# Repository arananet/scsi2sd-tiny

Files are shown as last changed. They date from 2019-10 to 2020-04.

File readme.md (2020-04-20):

# SCSI2SD

SCSI2SD is an open project made by Michael McMaster that replace your old SCSI drive device with a SCSI emulator using micro-sd.

# SCSI-TINY

I made this new tiny design from the original SCSI2SD schematics using EAGLE PCB Software. This particular design contains two SD sockets, one for micro-sd and one for SD. This is a working and tested design by many users. They are on sale in AmigaStore and also a batch has been made in 2018 for the RETROWIKI forum.

# Updates

25/10/2019: Initial release. HW made in 2018.

# License

SCSI2SD copyright (c) Michael McMaster | http://www.codesrc.com/mediawiki/index.php?title=SCSI2SD

SCSI2SD-Tiny copyright (c) 2018 Eduardo Arana | @edu_arana

This project is released under the GNU v3 license. You can redistribute it and/or modify it under the terms of the GNU General Public License as published by the Free Software Foundation, either version 3 of the License, or (at your option) any later version.

This program is distributed in the hope that it will be useful, but WITHOUT ANY WARRANTY.

See the GNU General Public License for more details.

There is a copy of the GPLv3 license in this repository. If not, see http://www.gnu.org/licenses/.

## The source/designs of any modifications must be provided to those you distribute the board to.

# Feedback

If you find any error on this description, please drop me an email to info@arananet.net or # Feedback

If you find any error on this description, please drop me an email to info@arananet.net or If you like the project or want to support it, you can buy me a beer or a KO-FI :) 


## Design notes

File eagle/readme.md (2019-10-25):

If you are gonna produce a batch of this board remember to quote the original authors, don't be a pcb lammer, leave the original authors on the PCB.

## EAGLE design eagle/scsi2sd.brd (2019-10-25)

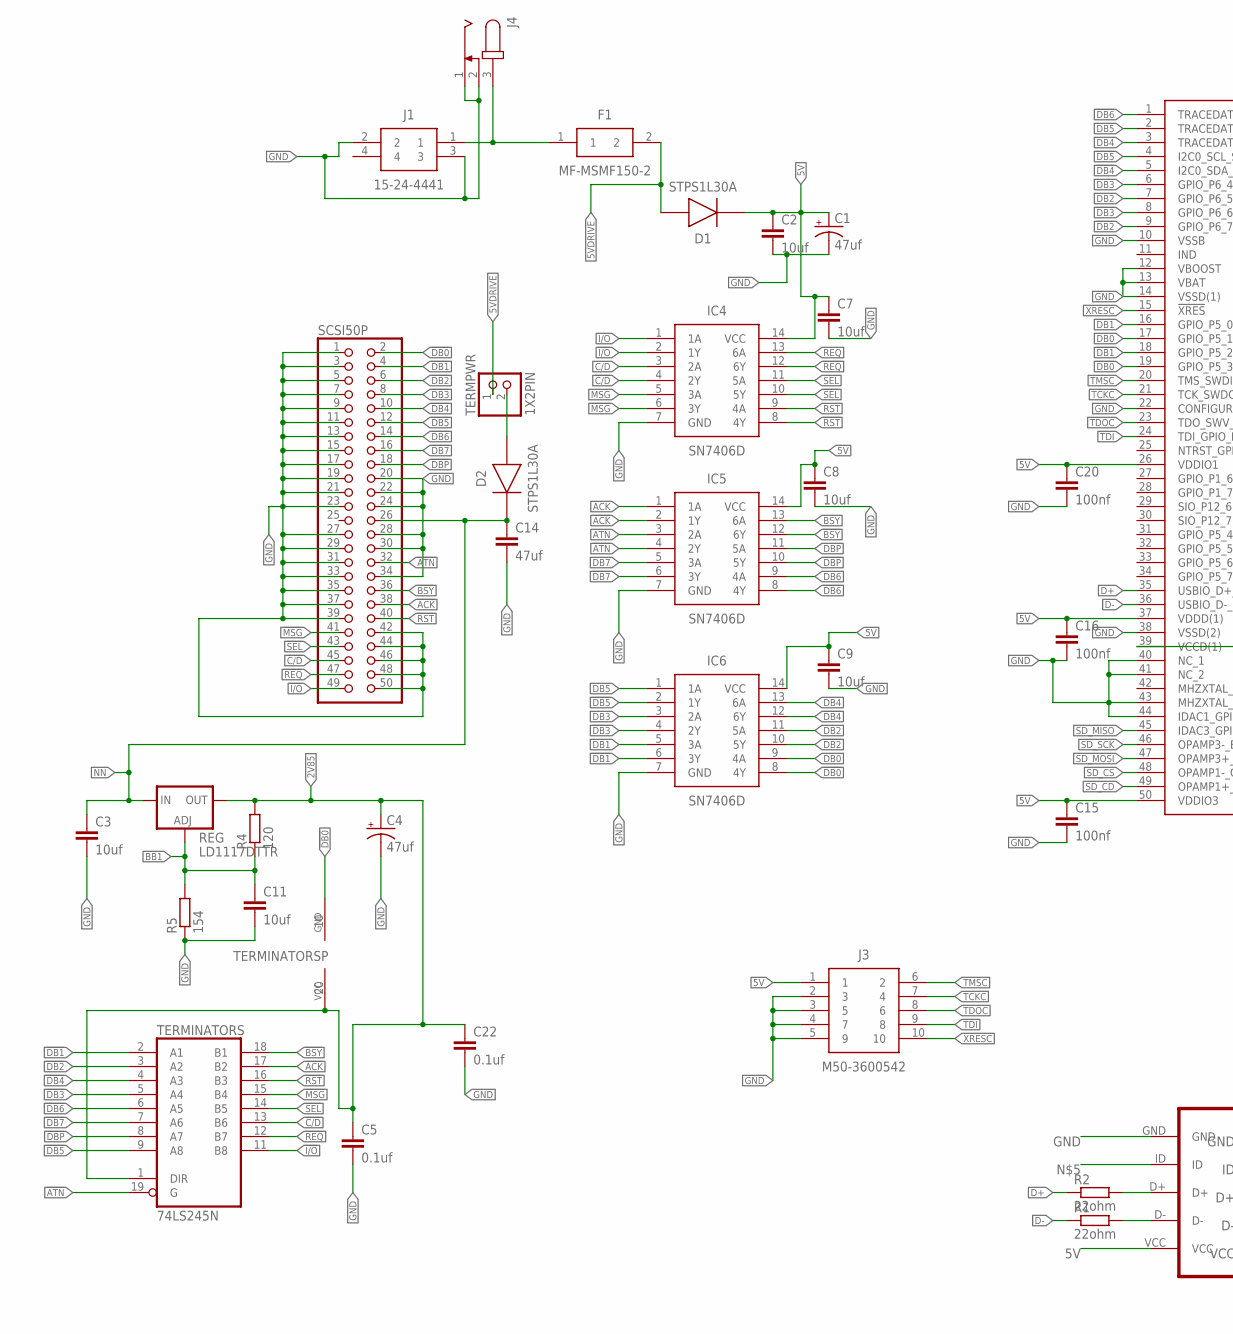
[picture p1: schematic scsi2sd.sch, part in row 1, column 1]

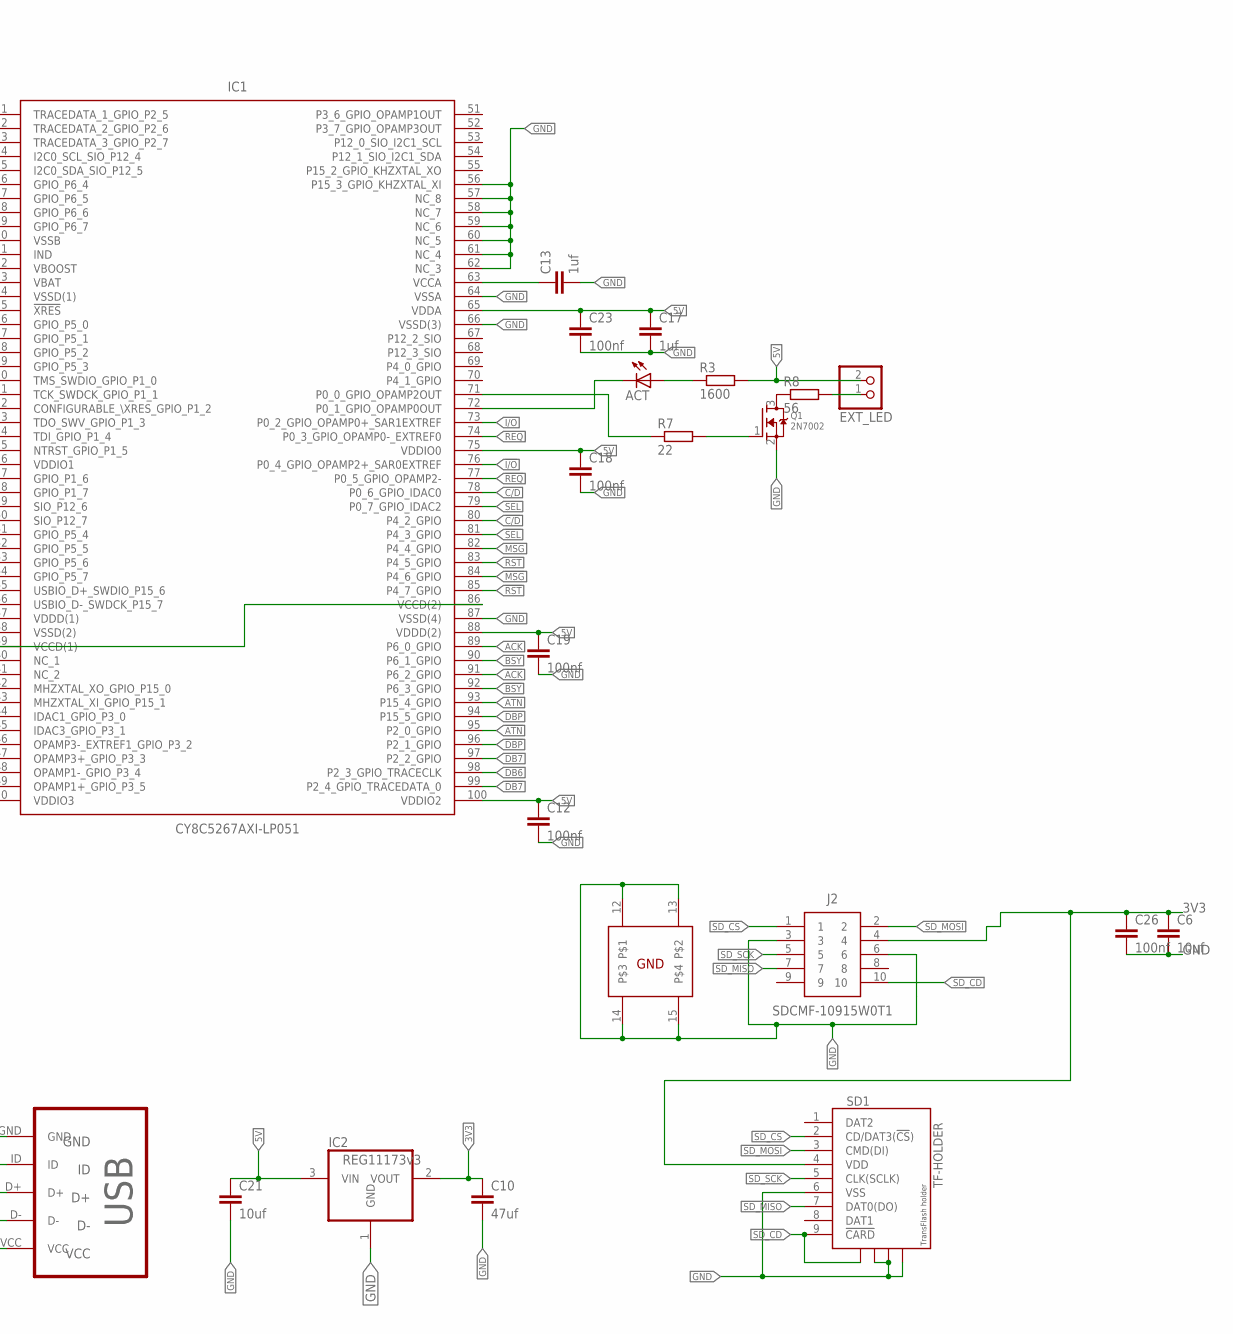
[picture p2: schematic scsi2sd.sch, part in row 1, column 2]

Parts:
ACT: LEDCHIPLED_0805; CHIPLED_0805
C1, C4: 47uf; E2,5-5
C2, C3, C6, C7, C8, C9, C11, C21: 10uf; C0603
C5, C22: 0.1uf; C0603
C10: 47uf; C0603
C12, C15, C16, C18, C19, C20, C23, C26: 100nf; C0603
C13, C17: 1uf; C0603
C14: 47uf; C1206
D1, D2: STPS1L30A; DIOM5226X223N
EXT_LED: 1X2PIN
F1: MF-MSMF150-2; FUSC4632X85N
IC1: CY8C5267AXI-LP051; TQFP50P1600X1600X160-100N
IC2: REG11173v3; SOT223
IC4, IC5, IC6: SN7406D; SOIC127P600X175-14N
J1: 15-24-4441
J2: SDCMF-10915W0T1
J3: M50-3600542; HARWIN_10PIN_1.27PITCH_SMD
J4: RAPC7120; RAPC712
Q1: 2N7002; SOT23
R1, R2: 22ohm; R0603
R3: 1600; R0603
R4: 120; R0603
R5: 154; R0603
R7: 22; R0603
R8: 56; R0603
REG: LD1117DTTR; DPACK
SCSI50P: PINHD-2X25/90; 2X25/90
SD1: TF-HOLDER; TF-PULL
TERMINATORS: 74LS245N; DIL20
TERMPWR: 1X2PIN
USB: MICRO-USB-B; MICRO_USB_4_LEGS

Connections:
2V85: C4.+, C5.1, C22.1, R4.2, REG.4 (OUT), TERMINATORS.1 (DIR), TERMINATORS.20 (VCC)
3V3: C6.1, C10.1, C26.1, IC2.2 (VOUT), J2.4, SD1.4 (VDD)
5V: C1.+, C2.1, C7.1, C8.1, C9.1, C12.1, C15.1, C16.1, C17.1, C18.1, C19.1, C20.1, C21.1, C23.1, D1.1 (K), EXT_LED.2, IC1.26 (VDDIO1), IC1.37 (VDDD(1)), IC1.50 (VDDIO3), IC1.65 (VDDA), IC1.75 (VDDIO0), IC1.88 (VDDD(2)), IC1.100 (VDDIO2), IC2.3 (VIN), IC4.14 (VCC), IC5.14 (VCC), IC6.14 (VCC), J3.1, R3.2, USB.VCC
5VDRIVE: D1.2 (A), F1.2, TERMPWR.1
!ACK: IC1.91 (P6_2_GPIO), IC5.2 (1Y), SCSI50P.38, TERMINATORS.17 (B2)
!ATN: IC1.95 (P2_0_GPIO), IC5.4 (2Y), SCSI50P.32, TERMINATORS.19 (G)
!BSY: IC1.92 (P6_3_GPIO), IC5.12 (6Y), SCSI50P.36, TERMINATORS.18 (B1)
!C/D: IC1.80 (P4_2_GPIO), IC4.4 (2Y), SCSI50P.45, TERMINATORS.13 (B6)
!DB0: IC1.19 (GPIO_P5_3), IC6.8 (4Y), SCSI50P.2, TERMINATORS.10 (GND)
!DB1: IC1.18 (GPIO_P5_2), IC6.6 (3Y), SCSI50P.4, TERMINATORS.2 (A1)
!DB2: IC1.9 (GPIO_P6_7), IC6.10 (5Y), SCSI50P.6, TERMINATORS.3 (A2)
!DB3: IC1.8 (GPIO_P6_6), IC6.4 (2Y), SCSI50P.8, TERMINATORS.5 (A4)
!DB4: IC1.5 (I2C0_SDA_SIO_P12_5), IC6.12 (6Y), SCSI50P.10, TERMINATORS.4 (A3)
!DB5: IC1.4 (I2C0_SCL_SIO_P12_4), IC6.2 (1Y), SCSI50P.12, TERMINATORS.9 (A8)
!DB6: IC1.1 (TRACEDATA_1_GPIO_P2_5), IC5.8 (4Y), SCSI50P.14, TERMINATORS.6 (A5)
!DB7: IC1.99 (P2_4_GPIO_TRACEDATA_0), IC5.6 (3Y), SCSI50P.16, TERMINATORS.7 (A6)
!DBP: IC1.96 (P2_1_GPIO), IC5.10 (5Y), SCSI50P.18, TERMINATORS.8 (A7)
!I/O: IC1.76 (P0_4_GPIO_OPAMP2+_SAR0EXTREF), IC4.2 (1Y), SCSI50P.49, TERMINATORS.11 (B8)
!MSG: IC1.84 (P4_6_GPIO), IC4.6 (3Y), SCSI50P.41, TERMINATORS.15 (B4)
!REQ: IC1.77 (P0_5_GPIO_OPAMP2-), IC4.12 (6Y), SCSI50P.47, TERMINATORS.12 (B7)
!RST: IC1.85 (P4_7_GPIO), IC4.8 (4Y), SCSI50P.40, TERMINATORS.16 (B3)
!SEL: IC1.81 (P4_3_GPIO), IC4.10 (5Y), SCSI50P.43, TERMINATORS.14 (B5)
ACK: IC1.89 (P6_0_GPIO), IC5.1 (1A)
ATN: IC1.93 (P15_4_GPIO), IC5.3 (2A)
BB1: C11.1, R4.1, R5.2, REG.1 (ADJ)
BSY: IC1.90 (P6_1_GPIO), IC5.13 (6A)
C/D: IC1.78 (P0_6_GPIO_IDAC0), IC4.3 (2A)
D+: IC1.35 (USBIO_D+_SWDIO_P15_6), R2.1
D-: IC1.36 (USBIO_D-_SWDCK_P15_7), R1.1
DB0: IC1.17 (GPIO_P5_1), IC6.9 (4A)
DB1: IC1.16 (GPIO_P5_0), IC6.5 (3A)
DB2: IC1.7 (GPIO_P6_5), IC6.11 (5A)
DB3: IC1.6 (GPIO_P6_4), IC6.3 (2A)
DB4: IC1.3 (TRACEDATA_3_GPIO_P2_7), IC6.13 (6A)
DB5: IC1.2 (TRACEDATA_2_GPIO_P2_6), IC6.1 (1A)
DB6: IC1.98 (P2_3_GPIO_TRACECLK), IC5.9 (4A)
DB7: IC1.97 (P2_2_GPIO), IC5.5 (3A)
DBP: IC1.94 (P15_5_GPIO), IC5.11 (5A)
GND: C1.-, C2.2, C3.2, C4.-, C5.2, C6.2, C7.2, C8.2, C9.2, C10.2, C11.2, C12.2, C13.2, C14.2, C15.2, C16.2, C17.2, C18.2, C19.2, C20.2, C21.2, C22.2, C23.2, C26.2, IC1.10 (VSSB), IC1.12 (VBOOST), IC1.13 (VBAT), IC1.14 (VSSD(1)), IC1.22 (CONFIGURABLE_\XRES_GPIO_P1_2), IC1.38 (VSSD(2)), IC1.40 (NC_1), IC1.41 (NC_2), IC1.43 (MHZXTAL_XI_GPIO_P15_1), IC1.44 (IDAC1_GPIO_P3_0), IC1.56 (P15_3_GPIO_KHZXTAL_XI), IC1.57 (NC_8), IC1.58 (NC_7), IC1.59 (NC_6), IC1.60 (NC_5), IC1.61 (NC_4), IC1.62 (NC_3), IC1.64 (VSSA), IC1.66 (VSSD(3)), IC1.87 (VSSD(4)), IC2.1 (GND), IC4.7 (GND), IC5.7 (GND), IC6.7 (GND), J1.2, J1.3, J2.3, J2.6, J2.12, J2.13, J2.14, J2.15, J3.2 (3), J3.3 (5), J3.4 (7), J3.5 (9), J4.1, J4.2, Q1.2 (S), R5.1, SCSI50P.1, SCSI50P.3, SCSI50P.5, SCSI50P.7, SCSI50P.9, SCSI50P.11, SCSI50P.13, SCSI50P.15, SCSI50P.17, SCSI50P.19, SCSI50P.20, SCSI50P.21, SCSI50P.22, SCSI50P.23, SCSI50P.24, SCSI50P.27, SCSI50P.28, SCSI50P.29, SCSI50P.30, SCSI50P.31, SCSI50P.33, SCSI50P.34, SCSI50P.35, SCSI50P.37, SCSI50P.39, SCSI50P.42, SCSI50P.44, SCSI50P.46, SCSI50P.48, SCSI50P.50, SD1.6 (VSS), SD1.S2, SD1.S3, SD1.S4, USB.GND
I/O: IC1.73 (P0_2_GPIO_OPAMP0+_SAR1EXTREF), IC4.1 (1A)
MSG: IC1.82 (P4_4_GPIO), IC4.5 (3A)
unnamed: F1.1, J1.1, J4.3
unnamed: R2.2, USB.D+
unnamed: R1.2, USB.D-
unnamed: ACT.A, R3.1
unnamed: IC1.71 (P0_0_GPIO_OPAMP2OUT), R7.1
unnamed: D2.2 (A), TERMPWR.2
unnamed: IC1.39 (VCCD(1)), IC1.86 (VCCD(2))
unnamed: Q1.1 (G), R7.2
unnamed: Q1.3 (D), R8.1
unnamed: EXT_LED.1, R8.2
unnamed: C13.1, IC1.63 (VCCA)
unnamed: ACT.C, IC1.72 (P0_1_GPIO_OPAMP0OUT)
NN: C3.1, C14.1, D2.1 (K), REG.3 (IN), SCSI50P.26
REQ: IC1.74 (P0_3_GPIO_OPAMP0-_EXTREF0), IC4.13 (6A)
RST: IC1.83 (P4_5_GPIO), IC4.9 (4A)
SD_CD: IC1.49 (OPAMP1+_GPIO_P3_5), J2.10, SD1.9 (!CARD), SD1.S1
SD_CS: IC1.48 (OPAMP1-_GPIO_P3_4), J2.1, SD1.2 (CD/DAT3(!CS!))
SD_MISO: IC1.45 (IDAC3_GPIO_P3_1), J2.7, SD1.7 (DAT0(DO))
SD_MOSI: IC1.47 (OPAMP3+_GPIO_P3_3), J2.2, SD1.3 (CMD(DI))
SD_SCK: IC1.46 (OPAMP3-_EXTREF1_GPIO_P3_2), J2.5, SD1.5 (CLK(SCLK))
SEL: IC1.79 (P0_7_GPIO_IDAC2), IC4.11 (5A)
TCKC: IC1.21 (TCK_SWDCK_GPIO_P1_1), J3.7 (4)
TDI: IC1.24 (TDI_GPIO_P1_4), J3.9 (8)
TDOC: IC1.23 (TDO_SWV_GPIO_P1_3), J3.8 (6)
TMSC: IC1.20 (TMS_SWDIO_GPIO_P1_0), J3.6 (2)
XRESC: IC1.15 (!XRES), J3.10

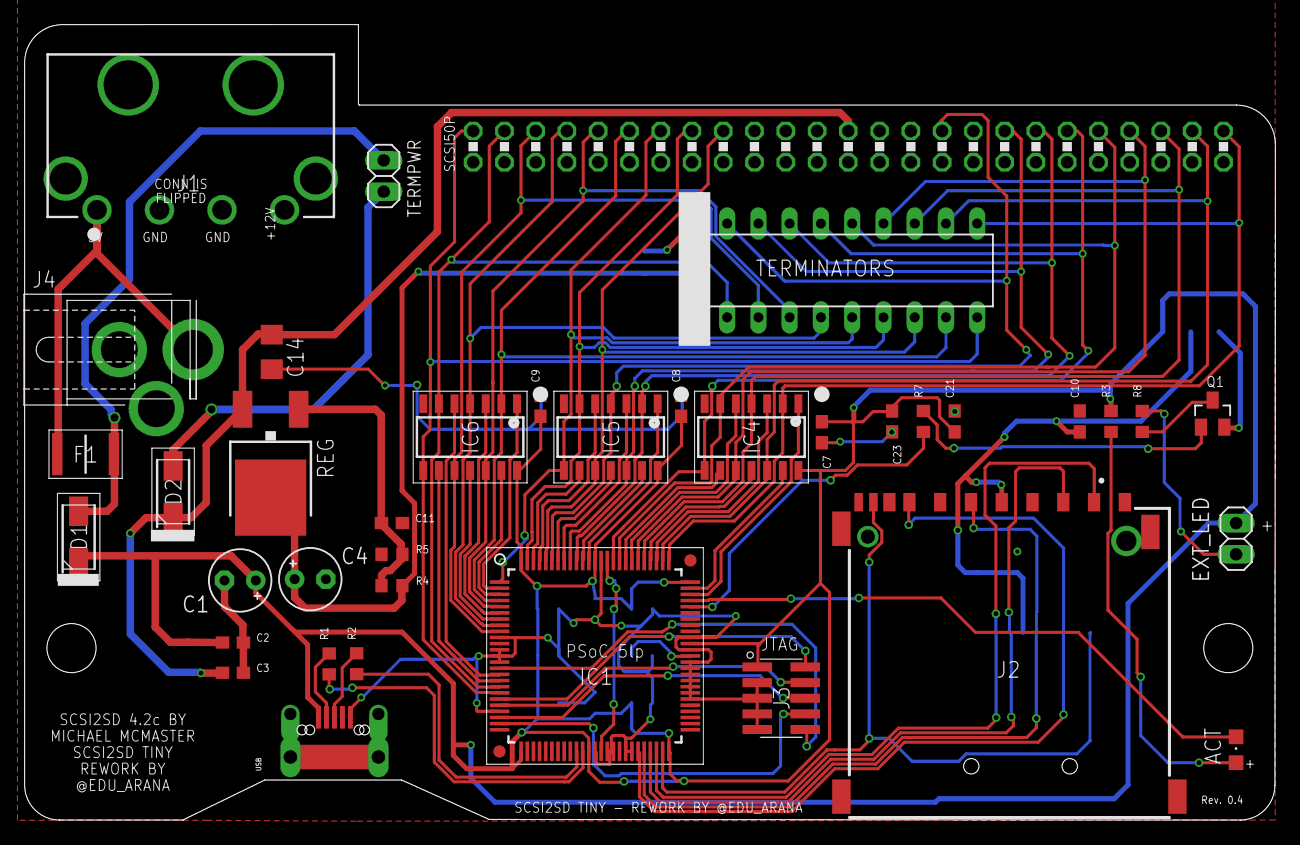
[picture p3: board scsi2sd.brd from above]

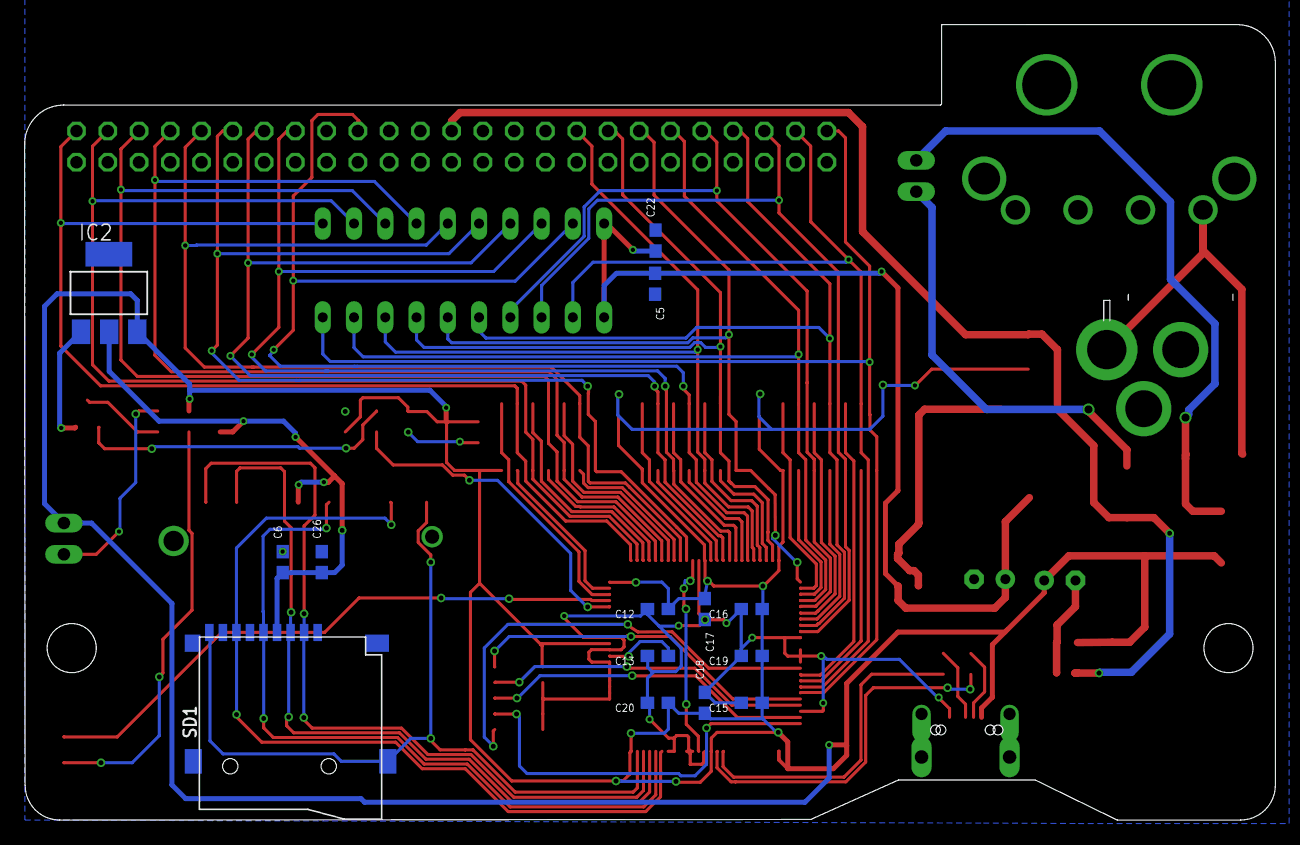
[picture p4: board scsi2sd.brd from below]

Board: 2 copper layers, 101.6 x 64.6 mm, 52 parts (14 on the bottom side), 67 nets.

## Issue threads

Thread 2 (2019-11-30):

Bill Of Material

Sch-LikA, 2019-11-30:
Hi Guys,

Love your work, this rework seems very well done. Could you just provide a BOM ? I'd like to build one or two.

Thanks !

Sch-LikA, 2020-03-05:
OK got it in Eagle, all good!

Closed 2020-03-05.
